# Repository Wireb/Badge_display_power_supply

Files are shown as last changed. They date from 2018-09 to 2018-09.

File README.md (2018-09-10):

# Badge display power supply
This design is a dual 6V to 18V input to settable 1.5A output switching regulator supply.   
Main purpose is to power up conference badges in display cases.   
  
The output voltage is set by R8 and R10. Pick the proper resistor value based on the table below:

|Rx|output V|Typical use|
| --- | --- | --- |
|7.68k|5V|USB powered|
|8.66k|4.5V|3x AA/AAA replacement|
|13k|3.3V|LiPo replacement mid charge|
|14.7k|3V|coin cell or 2x AA/AAA replacement|

**NOTE you MUST remove the battery when using this design as a battery replacement!**

J1, J2, and J3 are supply side input / output jacks. Cards are designed to be daisy chained between display using 5.5x2.5mm cables  
J4, J5, J6, J7, and J8 are output 1 controlled by R8  
J9, J10, J11, J12, and J13 are output 2 controlled by R10  
Populate connectors based on your needs.  

Thinking about making a smaller / cheaper single reg version as well in the future. 

## KiCad
This is a KiCad 5.0 project. 

## documentation
This is a XLS/PDF dump of the spreadsheet documentation I was using during development. 

## OSHpark PCBs
PCB design can be found here:
https://www.oshpark.com/shared_projects/n03EZh99

Copyright (c) 2018 Peter Shabino

Permission is hereby granted, free of charge, to any person obtaining a copy of this hardware, software, and associated documentation files 
(the "Product"), to deal in the Product without restriction, including without limitation the rights to use, copy, modify, merge, publish, 
distribute, sublicense, and/or sell copies of the Product, and to permit persons to whom the Product is furnished to do so, subject to the 
following conditions:

The above copyright notice and this permission notice shall be included in all copies or substantial portions of the Product.

THE PRODUCT IS PROVIDED "AS IS", WITHOUT WARRANTY OF ANY KIND, EXPRESS OR IMPLIED, INCLUDING BUT NOT LIMITED TO THE WARRANTIES OF 
MERCHANTABILITY, FITNESS FOR A PARTICULAR PURPOSE AND NONINFRINGEMENT. IN NO EVENT SHALL THE AUTHORS OR COPYRIGHT HOLDERS BE LIABLE 
FOR ANY CLAIM, DAMAGES OR OTHER LIABILITY, WHETHER IN AN ACTION OF CONTRACT, TORT OR OTHERWISE, ARISING FROM, OUT OF OR IN CONNECTION 
WITH THE PRODUCT OR THE USE OR OTHER DEALINGS IN THE PRODUCT.

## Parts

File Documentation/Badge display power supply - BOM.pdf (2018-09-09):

3 | $17.88
Q part number | footprint | ref_des | cost | extended | ext cost | link
2 100k | Resistors_SMD:R_0603 | R2 R4 | $0.10 | 6 | $0.60 https://www.digikey.com/product-detail/en/bourns-inc/CR0603-FX-1003HLF/CR0603-FX-1003HLFCT-ND/4247695
2 1uF | Capacitors_SMD:C_0603 | C3 C4 | $0.10 | 6 | $0.60 https://www.digikey.com/product-detail/en/samsung-electro-mechanics/CL10A105KA8NNNC/1276-1102-1-ND/3889188
4 22uF | Capacitors_SMD:C_0805 | C1 C5 C2 C6 | $0.66 | 12 | $7.92 https://www.digikey.com/product-detail/en/murata-electronics-north-america/GRT21BR61E226ME13L/490-12389-1-ND/5417090
2 40.2k | Resistors_SMD:R_0603 | R7 R9 | $0.10 | 6 | $0.60 https://www.digikey.com/product-detail/en/stackpole-electronics-inc/RMCF0603FT40K2/RMCF0603FT40K2CT-ND/1943095
2 | 499 Resistors_SMD:R_0603 | R11 R12 | $0.10 | 6 | $0.60 https://www.digikey.com/product-detail/en/yageo/RC0603FR-07499RL/311-499HRCT-ND/730213
2 499k | Resistors_SMD:R_0603 | R1 R3 | $0.10 | 6 | $0.60 https://www.digikey.com/product-detail/en/panasonic-electronic-components/ERJ-3EKF4993V/P499KHCT-ND/198415
2 59k | Resistors_SMD:R_0603 | R5 R6 | $0.10 | 6 | $0.60 https://www.digikey.com/product-detail/en/panasonic-electronic-components/ERJ-3EKF5902V/P59.0KHCT-ND/198449
2 6.5uH | Yuden:Yuden_Inductor_4.9x4.9 | L1 L2 | $0.38 | 6 | $2.28 https://www.digikey.com/product-detail/en/taiyo-yuden/NRS5030T6R8MMGJ/587-3462-1-ND/4157802
2 7.68k | Resistors_SMD:R_0603 | R8 R10 | $0.10 | 6 | $0.60 https://www.digikey.com/product-detail/en/panasonic-electronic-components/ERJ-3EKF7681V/P7.68KHCT-ND/198491
2 AP65111 | TO_SOT_Packages_SMD:SOT-23-6 | U1 U2 | $0.44 | 6 | $2.64 https://www.digikey.com/product-detail/en/diodes-incorporated/AP65111AWU-7/AP65111AWU-7DICT-ND/7652826
2 LED_red | LEDs:LED_0603 | D1 D2 | $0.14 | 6 | $0.84 https://www.digikey.com/product-detail/en/wurth-electronics-inc/150060RS75000/732-4978-1-ND/4489899
0 Metroid | PJS-icons:metroid | icon1 | 0 | $0.00
2 PJ-102BH | PJS-pth-parts:CUI_PJ-102BH | J1 J2 | $0.77 | 6 | $4.62 https://www.digikey.com/products/en?keywords=PJ-102BH
4 SS-52100-001 | PJS-pth-parts:Stewart_USB_SS-52100-001 | J7 J8 J12 J13 | $0.42 | 12 | $5.04 https://www.digikey.com/products/en?keywords=SS-52100-001
0 Screw | Degson:DG301-5.002P-12 | J3 J6 J5 J4 J11 J10 J9 | 0 | $0.00
2 | 8.66k | $0.10 | 6 | $0.60 https://www.digikey.com/product-detail/en/yageo/RC0603FR-078K66L/311-8.66KHRCT-ND/730340
2 | 13k | $0.10 | 6 | $0.60 https://www.digikey.com/product-detail/en/yageo/RC0603FR-0713KL/311-13.0KHRCT-ND/729876
2 | 14.7k | $0.10 | 6 | $0.60 https://www.digikey.com/product-detail/en/panasonic-electronic-components/ERJ-3EKF1472V/P14.7KHCT-ND/198164

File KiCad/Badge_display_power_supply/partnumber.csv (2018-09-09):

Q | part number | footprint | ref_des
2 | 100k | Resistors_SMD:R_0603 | R2 R4
2 | 1uF | Capacitors_SMD:C_0603 | C3 C4
4 | 22uF | Capacitors_SMD:C_0805 | C1 C5 C2 C6
2 | 40.2k | Resistors_SMD:R_0603 | R7 R9
2 | 499 | Resistors_SMD:R_0603 | R11 R12
2 | 499k | Resistors_SMD:R_0603 | R1 R3
2 | 59k | Resistors_SMD:R_0603 | R5 R6
2 | 6.5uH | Yuden:Yuden_Inductor_4.9x4.9 | L1 L2
2 | 7.68k | Resistors_SMD:R_0603 | R8 R10
2 | AP65111 | TO_SOT_Packages_SMD:SOT-23-6 | U1 U2
2 | LED_red | LEDs:LED_0603 | D1 D2
1 | Metroid | PJS-icons:metroid | icon1
2 | PJ-102BH | PJS-pth-parts:CUI_PJ-102BH | J1 J2
4 | SS-52100-001 | PJS-pth-parts:Stewart_USB_SS-52100-001 | J7 J8 J12 J13
7 | Screw | Degson:DG301-5.002P-12 | J3 J6 J5 J4 J11 J10 J9

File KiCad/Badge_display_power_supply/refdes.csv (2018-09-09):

ref_des | part number | footprint
C1 | 22uF | Capacitors_SMD:C_0805
C2 | 22uF | Capacitors_SMD:C_0805
C3 | 1uF | Capacitors_SMD:C_0603
C4 | 1uF | Capacitors_SMD:C_0603
C5 | 22uF | Capacitors_SMD:C_0805
C6 | 22uF | Capacitors_SMD:C_0805
D1 | LED_red | LEDs:LED_0603
D2 | LED_red | LEDs:LED_0603
J1 | PJ-102BH | PJS-pth-parts:CUI_PJ-102BH
J10 | Screw | Degson:DG301-5.002P-12
J11 | Screw | Degson:DG301-5.002P-12
J12 | SS-52100-001 | PJS-pth-parts:Stewart_USB_SS-52100-001
J13 | SS-52100-001 | PJS-pth-parts:Stewart_USB_SS-52100-001
J2 | PJ-102BH | PJS-pth-parts:CUI_PJ-102BH
J3 | Screw | Degson:DG301-5.002P-12
J4 | Screw | Degson:DG301-5.002P-12
J5 | Screw | Degson:DG301-5.002P-12
J6 | Screw | Degson:DG301-5.002P-12
J7 | SS-52100-001 | PJS-pth-parts:Stewart_USB_SS-52100-001
J8 | SS-52100-001 | PJS-pth-parts:Stewart_USB_SS-52100-001
J9 | Screw | Degson:DG301-5.002P-12
L1 | 6.5uH | Yuden:Yuden_Inductor_4.9x4.9
L2 | 6.5uH | Yuden:Yuden_Inductor_4.9x4.9
R1 | 499k | Resistors_SMD:R_0603
R10 | 7.68k | Resistors_SMD:R_0603
R11 | 499 | Resistors_SMD:R_0603
R12 | 499 | Resistors_SMD:R_0603
R2 | 100k | Resistors_SMD:R_0603
R3 | 499k | Resistors_SMD:R_0603
R4 | 100k | Resistors_SMD:R_0603
R5 | 59k | Resistors_SMD:R_0603
R6 | 59k | Resistors_SMD:R_0603
R7 | 40.2k | Resistors_SMD:R_0603
R8 | 7.68k | Resistors_SMD:R_0603
R9 | 40.2k | Resistors_SMD:R_0603
U1 | AP65111 | TO_SOT_Packages_SMD:SOT-23-6
U2 | AP65111 | TO_SOT_Packages_SMD:SOT-23-6
icon1 | Metroid | PJS-icons:metroid

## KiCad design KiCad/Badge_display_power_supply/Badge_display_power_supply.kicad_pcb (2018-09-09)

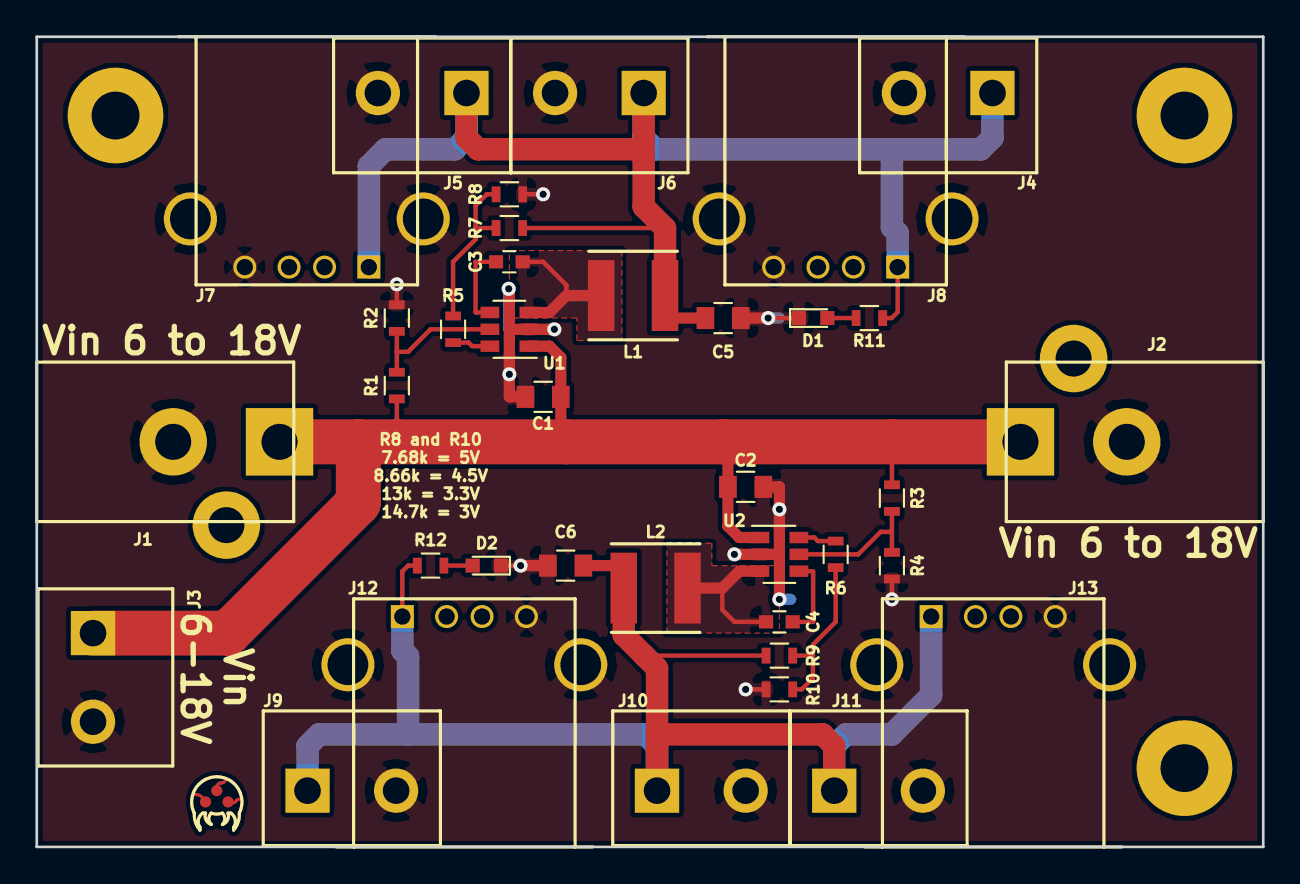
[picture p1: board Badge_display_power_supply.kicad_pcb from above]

Board: 2 copper layers, 69.2 x 45.7 mm, 38 parts (0 on the bottom side), 16 nets.

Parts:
C1, C2, C5, C6: 22uF; C_0805
C3, C4: 1uF; C_0603
D1, D2: LED_red; LED_0603
J1, J2: PJ-102BH; CUI_PJ-102BH
J3, J4, J5, J6, J9, J10, J11: Screw; DG301-5.002P-12
J7, J8, J12, J13: SS-52100-001; Stewart_USB_SS-52100-001
L1, L2: 6.5uH; Yuden_Inductor_4.9x4.9
R1, R3: 499k; R_0603
R2, R4: 100k; R_0603
R5, R6: 59k; R_0603
R7, R9: 40.2k; R_0603
R8, R10: 7.68k; R_0603
R11, R12: 499; R_0603
U1, U2: AP65111; SOT-23-6
icon1: Metroid; metroid

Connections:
GND: C1.2, C2.2, C5.2, C6.2, D1.1, D2.1, J1.2, J2.2, J3.2, J4.2, J5.2, J6.2, J7.4, J7.5, J8.4, J8.5, J9.2, J10.2, J11.2, J12.4, J12.5, J13.4, J13.5, R2.2, R4.2, R8.2, R10.2, U1.2, U2.2
unnamed: C1.1, C2.1, J1.1, J2.1, J3.1, R1.1, R3.1, U1.1, U2.1
unnamed: C3.1, L1.2, U1.3
unnamed: C3.2, U1.4
unnamed: C4.1, L2.2, U2.3
unnamed: C4.2, U2.4
unnamed: C5.1, J4.1, J5.1, J6.1, J7.1, J8.1, L1.1, R7.1, R11.1
unnamed: C6.1, J9.1, J10.1, J11.1, J12.1, J13.1, L2.1, R9.1, R12.1
unnamed: D1.2, R11.2
unnamed: D2.2, R12.2
unnamed: R1.2, R2.1, U1.5
unnamed: R3.2, R4.1, U2.5
unnamed: R5.1, R7.2, R8.1
unnamed: R5.2, U1.6
unnamed: R6.2, U2.6
unnamed: R6.1, R9.2, R10.1

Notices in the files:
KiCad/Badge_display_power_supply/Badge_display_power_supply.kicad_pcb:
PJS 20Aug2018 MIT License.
